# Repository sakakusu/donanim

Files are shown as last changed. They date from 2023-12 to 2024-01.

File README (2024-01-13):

githubı çözene kadar hiyerarşi yanlış olabilir.

ultrasonik yaklaşım sensörleri ile başlıyorum

**** ultra.png **** 
toplam 8 sensör olacak
Texas int firmasının PGA460-q1 çipini sensörü sürmek ve eko yu yeniden okumak için kullanacağım 
eğer istediğim doğruluğu alamazsam stm32l443 ile yeniden çizeceğim baskı devre basılıp gelene kadarki çizim ultra.kicad_sch dosyasının içinde
deneyebilmek için pcd sini de hazırlayacağım pcb si ultra.kicad.pcb dosyasının içinde çizim tahminen 3 ocak 24 te yüklenmiş olur

kısaca devre elemanlarını tanıtayım 
aşağıda analog mux var 24V a kadar multiplex yapıp yeni çip daha önemlisi kapasite ve ağır trafo kullanımını azaltıyor
MUX4051 i 24V la sürüp adres pinini 3.3 ile süreceğiz

devre üzerinde üç ayrı ground var bunları çizim yaparken kolaylık olsun diye çizdim çizim işim bitince tek noktada birleştireceğim 
pcb çizerken video çekebilirsem videoda sebeplerini anlatırım video çekemezsen daha detaylı resimlerle açıklarım
ultra kısmının maliyeti 6 usd civarı.

****** gyro.png ****
ikinci kısım navigasyon, manyetik sensör, gyro, accelerometre, sıcaklık sensörü ve barometre
manyetik sensör kuzeyi bulmak için(1g yi geçmeyeceğimiz için yer çekimini ölçmeden nümerik olarak hesaplayacağım
sıcaklık sensörü; manyetik sensörü kalibre etmek için manyetik alan ölçen sensörler sıcaklıktan daha fazla etkilenirler
60 dolara heading açısının doğruluğu 0.01 derece olan çip vardı, hobi projesi olduğu için daha ucuz bir alternatif seçtim
doğruluğu 0.05 derece.

BNO085 çipi accelerormeter, gyro, ve sıcaklık sensörü bulunduruyor
BME280 barometre  maalesef bosch ancak ucuz ve iş görüyor kullandım

navigasyon kısmı çok detaylı izaha muhtaç 
NEO M8Q 01A seçtim arabalar için imal edilmiş düşük sıcaklıkta halen doğru ölçer, hobi projesi ne kadar bu sınırlara ihtiyaç duyar 
sizin kararınız fork yaparsanız pin to pin ucuz muadilleri yine ublox ta var birini kullanın
bulutlu havalarda navigasyon yavaşlamasın diye antende kuvvetlendirici ve bir saw filtre kullandım 
murata filtre digikeyde yoktu ürün temini ile uğraşmayayım diye maalesef stokta olan infineon kullandım 
kimse kullanmayınca stok bize kalmış elemanların değerlerinin hesabını video çekersem anlatırım vakit 
bulamazsam yeni bir yazı hazırlayacağım çizim üzerinde tanıtmadığım işlemci kaldı 
kalman filtre hesaplayacağım ana işlemciye iletişim için yük düşmesin kalman filtreyi hesaplasın
istendiğinde matris halinde ultrasoniklerden uzaklıkları, navigasyonu gyro accel barometrik sensörleri tek parçada göndersin diye ekledim
80 Mhz ye çıkabiliyor elimde var diye seçtim texas işlemcisi olsa daha iyi olurdu hobi projesi olduğu için st de olsa çizdim
çizimdeki üçüncü avrupa malı ürün oldu maalesef. boş bir vakitte üçünü de amerikan muadilleri ile değiştiririm. 
100 pinli ürünü seçme sebebim; elimde çokça numune var, atmayayım bari quadcopter olsun.

*** mcu_port.png ***
içerisinde seçili portlar var bu sıralamaya göre mcu bağlantılarını yapacağım 
3 spi bir i2c bir usb dac adc vs açtım kullanılmayan portları yazılımla kapatacağım
kicaddeli şema kütüphanesini buna göre güncelledim

imu donanımı bitti 
1- motor sürücü 
2- single board computer nxp imx8 ile
3- güç yönetimi, şarj ve deşarj yönetimi 
devresi hazırladıktan sonra baskı devreleri tek kart olarak yeniden çizeceğim aşama aşama programlarını yüklerim
4-iletişim kısmını hazır alacağım proje bitmeden(6 aydan kısa sürer) birkaç kişi talep ederse kriptolu ferkans atlamalı bir şey de tasarlayabilirim 

3 unde yüklerim yazmıştım masaüstü bilgisayarı açamadım yüklemem gecikti 

mcu ile çalıştırdıktan sonra fpga ile yeniden hazırlamayı düşünüyordum 50 dolar giriş seviyesi artix7 bu sebeple burası sadece mcu olarak kalacak 
kalman filtresi de mcu da çalışacak yeniden çizmeyeceğim belki enerji uçuş birleştirip tek çip yaparım board imu.kica_brd dosyasının içinde
bir tane dizip fotoğraf yüklerim kalman yazması uzun sürmez ama denemesi vakit alır mart başı umarım

iki tasarım eş zamanlı yapacağım bir tanesi hızlı bir tanesi sessiz
motor sürücüyü de ben tasarlayacağım o zaman detaylarıyla anlatırım
sonraki metinleri oku1- oku2 isimli dosyalarda yazacağım

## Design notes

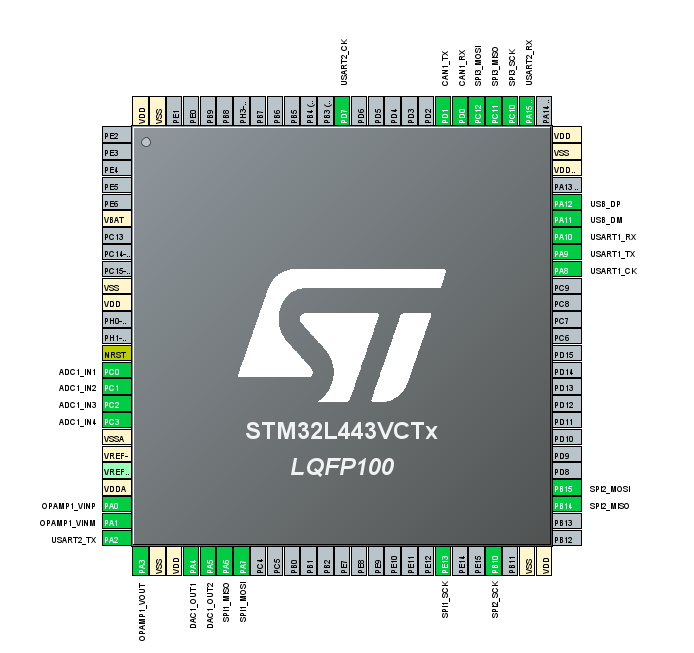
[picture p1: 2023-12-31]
mcu_port.PNG

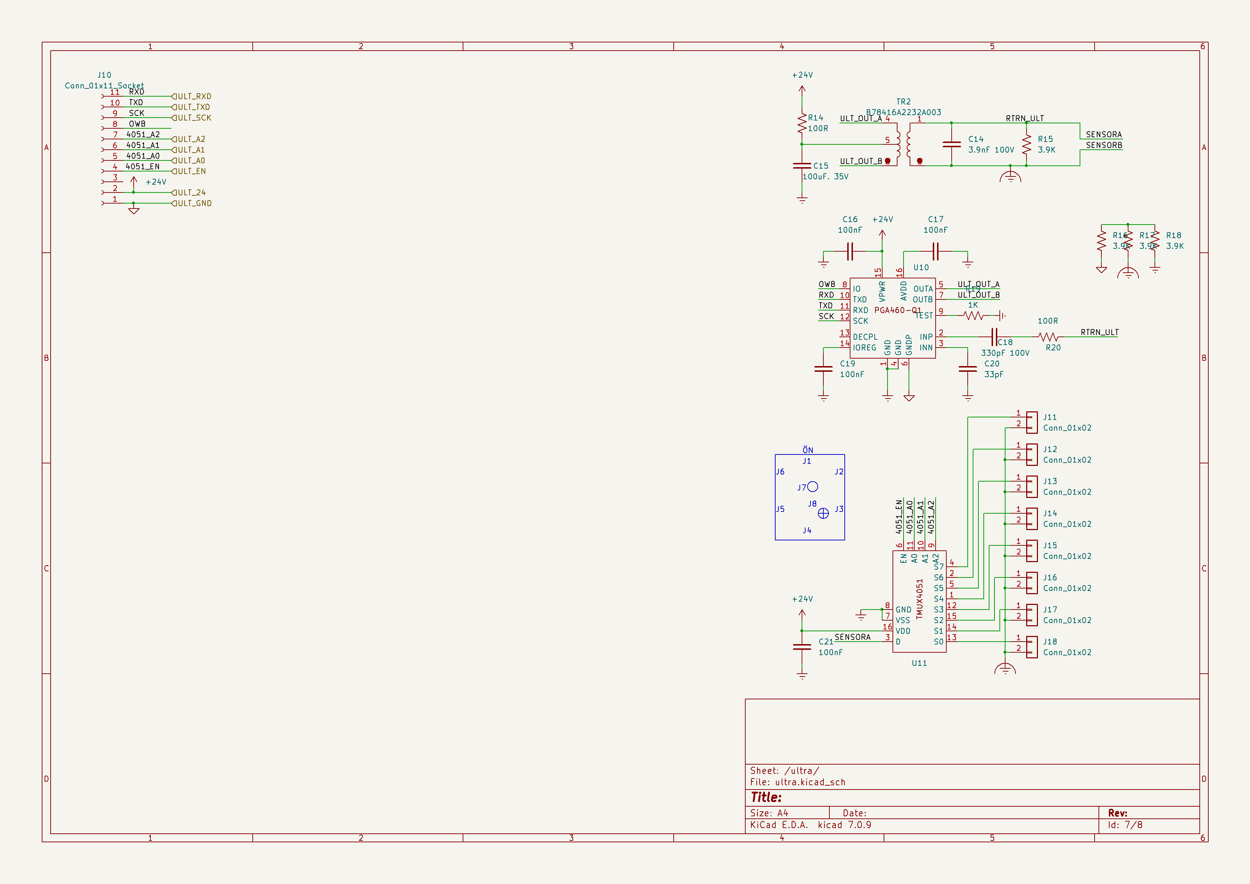
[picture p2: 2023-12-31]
ultra.png

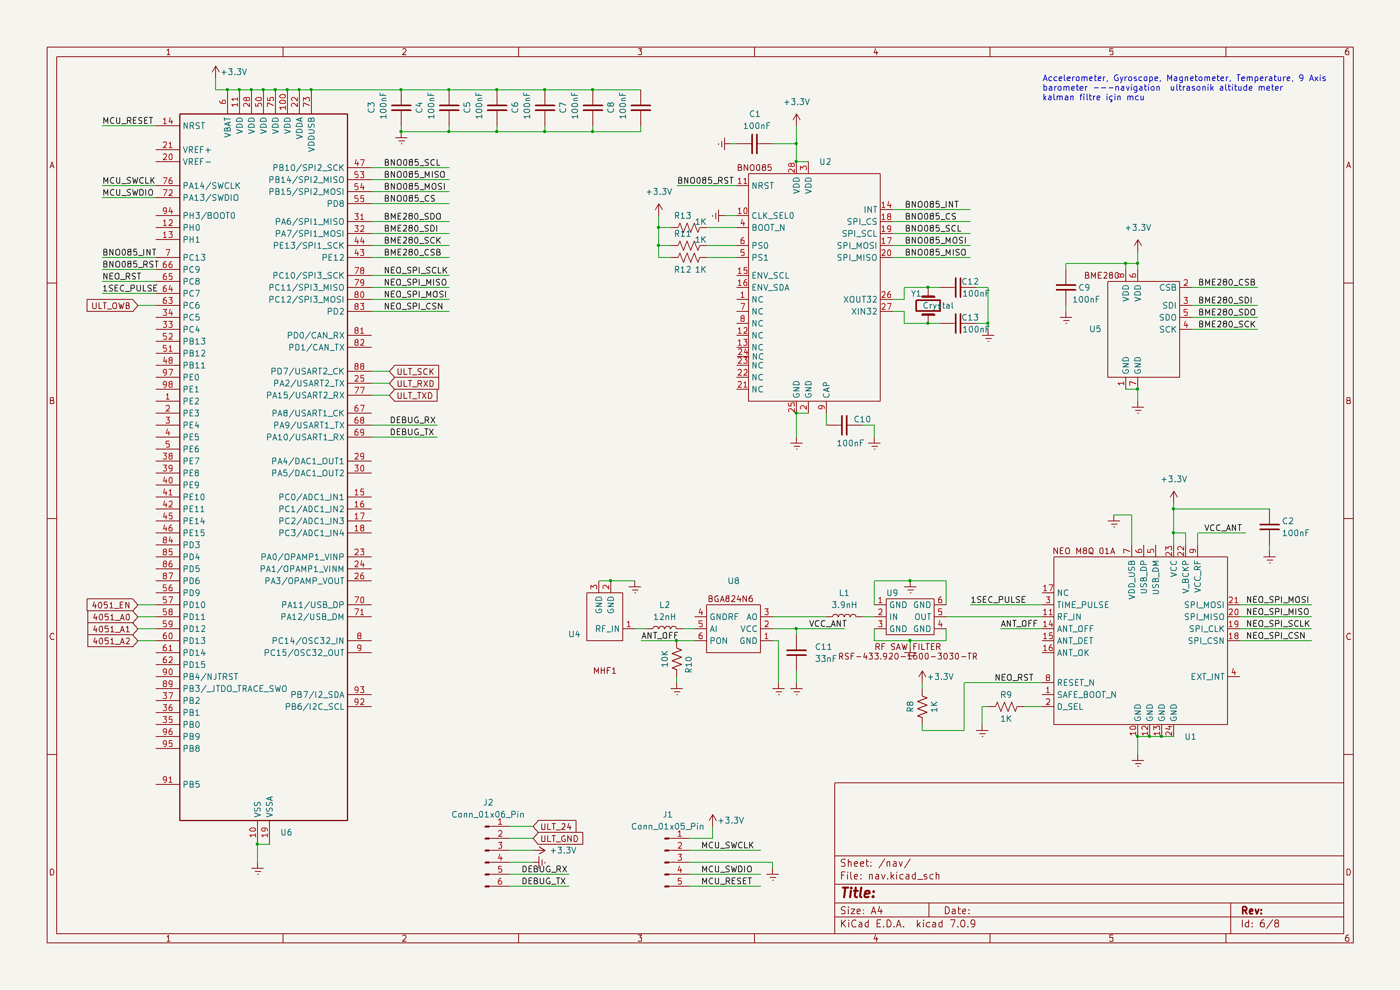
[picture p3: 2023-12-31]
gyro.png

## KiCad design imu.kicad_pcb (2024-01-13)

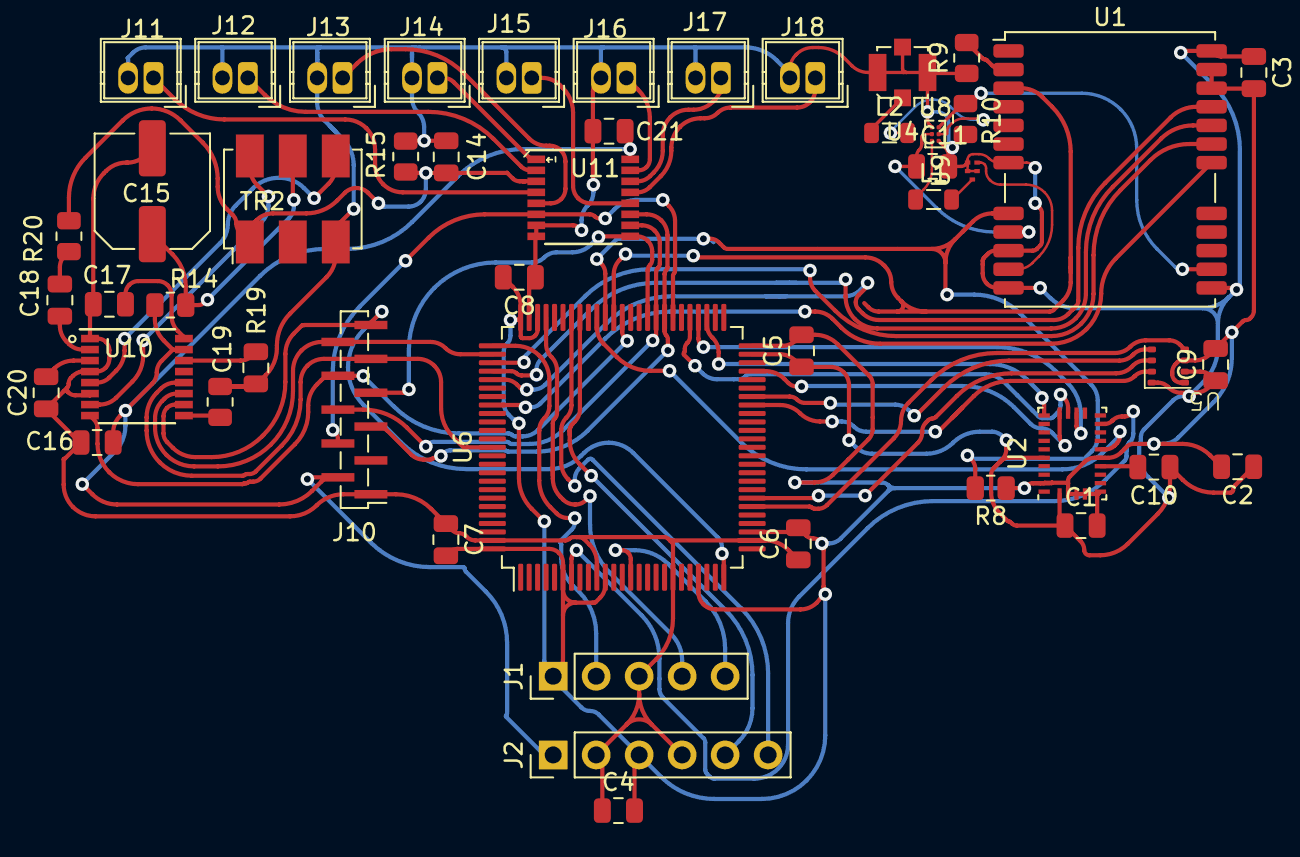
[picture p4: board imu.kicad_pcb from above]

Board: 2 copper layers, 49 parts (0 on the bottom side), 59 nets.

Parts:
C1, C2, C3, C4, C5, C6, C7, C8, C9, C10, C16, C17, C19, C21: 100nF; C_0805_2012Metric
C11: 33nF; C_0805_2012Metric
C14: 3.9nF 100V; C_0805_2012Metric
C15: 100uF. 35V; C_Elec_6.3x7.7
C18: 330pF 100V; C_0805_2012Metric
C20: 33pF; C_0805_2012Metric
J1: Conn_01x05_Pin; PinHeader_1x05_P2.54mm_Vertical
J2: Conn_01x06_Pin; PinHeader_1x06_P2.54mm_Vertical
J10: Conn_01x11_Socket; PinSocket_1x11_P1.00mm_Vertical_SMD_Pin1Left
J11, J12, J13, J14, J15, J16, J17, J18: Conn_01x02; Wuerth_WR-WTB_64800211622_1x02_P1.50mm_Vertical
L1: 3.9nH; L_0805_2012Metric
L2: 12nH; L_0805_2012Metric
R8, R9, R19: 1K; R_0805_2012Metric
R10: 10K; R_0805_2012Metric
R14: 0R; R_0805_2012Metric
R15: 3.9K; R_0805_2012Metric
R20: 100R; R_0805_2012Metric
TR2: B78416A2232A003; Mini-Circuits_CD542_H2.84mm
U1: ublox_NEO
U2: LGA-28_5.2x3.8mm_P0.5mm
U4: U.FL_Molex_MCRF_73412-0110_Vertical
U5: BME280
U6: LQFP-100_14x14mm_P0.5mm
U8: Infineon_PG-TSNP-6-10_0.7x1.1mm_0.7x1.1mm_P0.4mm
U9: SAW_FILTER
U10, U11: HTSSOP-16-1EP_4.4x5mm_P0.65mm_EP3.4x5mm

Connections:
4051_A0: J10.5, U6.58 (PD11), U11.11 (A0)
4051_A1: J10.6, U6.59 (PD12), U11.10 (A1)
4051_A2: J10.7, U6.60 (PD13), U11.9 (A2)
4051_EN: J10.4, U6.57 (PD10), U11.6 (EN)
+3.3V: C1.2, C2.2, C3.2, C4.2, C5.2, C6.2, C7.2, C8.2, C9.2, J1.1, J2.3, R8.1, U1.22 (V_BCKP), U1.23 (VCC), U2.3 (VDD), U2.4 (BOOT_N), U2.5 (PS1), U2.6 (PS0), U2.10 (CLK_SEL0), U2.28 (VDD), U5.6 (VDD), U5.8 (VDD), U6.6 (VBAT), U6.11 (VDD), U6.22 (VDDA), U6.28 (VDD), U6.50 (VDD), U6.73 (VDDUSB), U6.75 (VDD), U6.100 (VDD)
/nav/1SEC_PULSE: U1.3 (TIME_PULSE), U6.64 (PC7)
/nav/ANT_OFF: R10.2, U1.14 (ANT_OFF), U8.6 (PON)
/nav/BME280_CSB: U5.2 (CSB), U6.43 (PE12)
/nav/BME280_SCK: U5.4 (SCK), U6.44 (PE13/SPI1_SCK)
/nav/BME280_SDI: U5.3 (SDI), U6.32 (PA7/SPI1_MOSI)
/nav/BME280_SDO: U5.5 (SDO), U6.31 (PA6/SPI1_MISO)
/nav/BNO085_CS: U2.18 (SPI_CS), U6.55 (PD8)
/nav/BNO085_INT: U2.14 (INT), U6.7 (PC13)
/nav/BNO085_MISO: U2.20 (SPI_MISO), U6.53 (PB14/SPI2_MISO)
/nav/BNO085_MOSI: U2.17 (SPI_MOSI), U6.54 (PB15/SPI2_MOSI)
/nav/BNO085_RST: U2.11 (NRST), U6.66 (PC9)
/nav/BNO085_SCL: U2.19 (SPI_SCL), U6.47 (PB10/SPI2_SCK)
/nav/DEBUG_RX: J2.5, U6.68 (PA9/USART1_TX)
/nav/DEBUG_TX: J2.6, U6.69 (PA10/USART1_RX)
/nav/MCU_RESET: J1.5, U6.14 (NRST)
/nav/MCU_SWCLK: J1.2, U6.76 (PA14/SWCLK)
/nav/MCU_SWDIO: J1.4, U6.72 (PA13/SWDIO)
/nav/NEO_RST: R8.2, U1.8 (RESET_N), U6.65 (PC8)
/nav/NEO_SPI_CSN: U1.18 (SPI_CSN), U6.83 (PD2)
/nav/NEO_SPI_MISO: U1.20 (SPI_MISO), U6.79 (PC11/SPI3_MISO)
/nav/NEO_SPI_MOSI: U1.21 (SPI_MOSI), U6.80 (PC12/SPI3_MOSI)
/nav/NEO_SPI_SCLK: U1.19 (SPI_CLK), U6.78 (PC10/SPI3_SCK)
/nav/VCC_ANT: C11.2, U1.9 (VCC_RF), U8.2 (VCC)
/ultra/RTRN_ULT: C14.1, R15.1, R20.2, TR2.1, U11.3 (D)
/ultra/ULT_OUT_A: TR2.4, U10.5 (OUTA)
/ultra/ULT_OUT_B: TR2.6, U10.7 (OUTB)
unnamed: C15.1, R14.2, TR2.5
unnamed: C18.2, R20.1
unnamed: J11.1, U11.4 (S7)
unnamed: J12.1, U11.2 (S6)
unnamed: J13.1, U11.5 (S5)
unnamed: J14.1, U11.1 (S4)
unnamed: J15.1, U11.12 (S3)
unnamed: J16.1, U11.15 (S2)
unnamed: J17.1, U11.14 (S1)
unnamed: J18.1, U11.13 (S0)
unnamed: R9.2, U1.2 (D_SEL)
unnamed: U1.11 (RF_IN), U9.4 (OUT)
unnamed: C10.2, U2.9 (CAP)
unnamed: L2.1, U4.1 (RF_IN)
unnamed: L2.2, U8.5 (AI)
unnamed: L1.1, U8.3 (AO)
unnamed: L1.2, U9.1 (IN)
unnamed: C17.1, U10.16 (AVDD)
unnamed: C20.2, U10.3 (INN)
unnamed: C18.1, U10.2 (INP)
unnamed: C19.2, U10.14 (IOREG)
unnamed: R19.1, U10.9 (TEST)
ULT_24: C16.2, C21.2, J2.1, J10.2, R14.1, U10.15 (VPWR), U11.16 (VDD)
ULT_GND: C1.1, C2.1, C3.1, C4.1, C5.1, C6.1, C7.1, C8.1, C9.1, C10.1, C11.1, C14.2, C15.2, C16.1, C17.2, C19.1, C20.1, C21.1, J1.3, J2.2, J2.4, J10.1, J11.2, J12.2, J13.2, J14.2, J15.2, J16.2, J17.2, J18.2, R9.1, R10.1, R15.2, R19.2, TR2.3, U1.7 (VDD_USB), U1.10 (GND), U1.12 (GND), U1.13 (GND), U1.24 (GND), U2.2 (GND), U2.25 (GND), U4.2 (GND), U5.1 (GND), U5.7 (GND), U6.10 (VSS), U6.19 (VSSA), U6.27 (VSS), U6.49 (VSS), U6.74 (VSS), U6.99 (VSS), U8.1 (GND), U8.4 (GNDRF), U9.2 (GND), U9.3 (GND), U9.5 (GND), U10.1 (GND), U10.4 (GND), U10.6 (GNDP), U11.7 (VSS), U11.8 (GND)
ULT_OWB: J10.8, U6.63 (PC6), U10.8 (IO)
ULT_RXD: J10.11, U6.25 (PA2/USART2_TX), U10.10 (TXD)
ULT_SCK: J10.9, U6.88 (PD7/USART2_CK), U10.12 (SCK)
ULT_TXD: J10.10, U6.77 (PA15/USART2_RX), U10.11 (RXD)
